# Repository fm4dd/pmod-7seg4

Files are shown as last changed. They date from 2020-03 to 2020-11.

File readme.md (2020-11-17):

## 7SEG4 PMOD

### Description

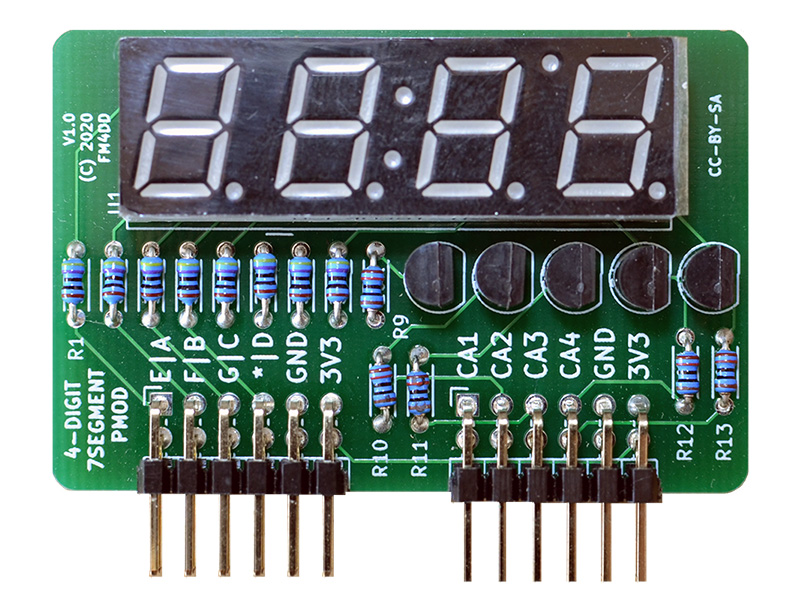
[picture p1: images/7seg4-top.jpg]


This PMOD provides a multiplexed four-digit 7-segment LED display output to FPGA designs via two double-row PMOD ports (quad-row).
The 7-segment display type "common anode" requires to use inverse logic. With inverse logic, setting the output "LOW" lights up the LED segment. Each digit has its own common anode, but the seven LED segments are shared. To display separate numbers on each digit, the program cycles through each anode with the apropriate segments enabled for this digit.

http://fpga.fm4dd.com/

### Schematic
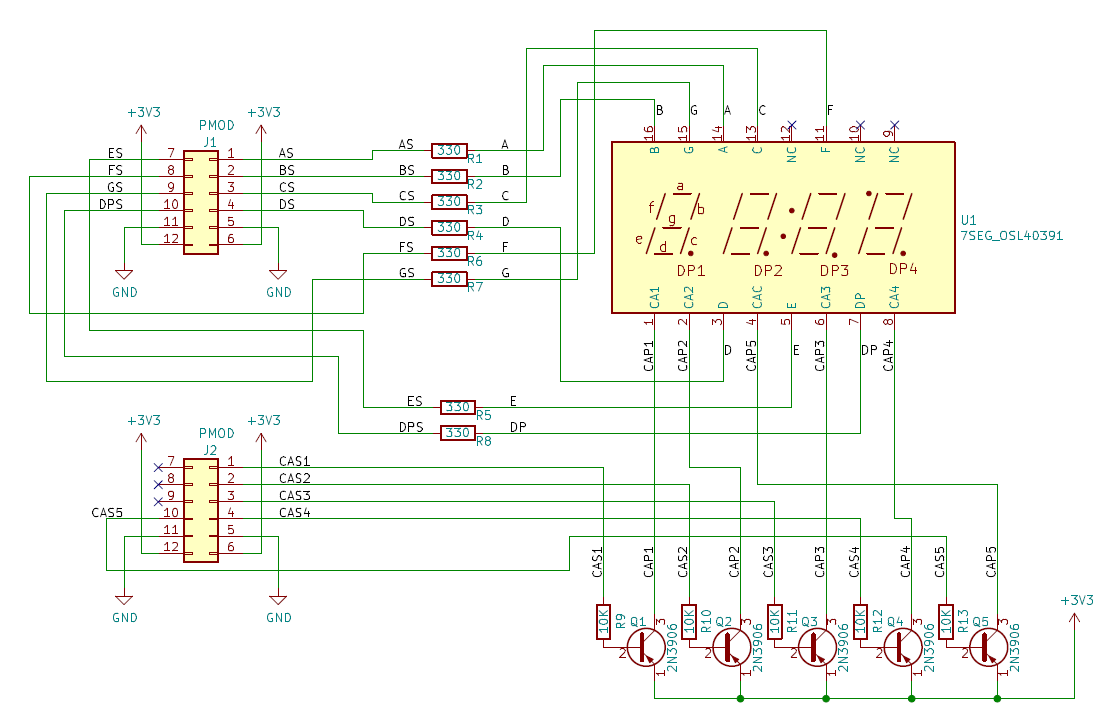
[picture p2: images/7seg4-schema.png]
7SEG4 PMOD Schematics


### PCB Gerber
[7SEG4 PMOD Gerber V1.1](20200130-7seg4-gerber-v11.zip)

### Pin Assignments

#### IceBreaker v1.0

 J1# |  Label | Description   | PMOD1A
-----|--------|---------------|-------
1    |  A     | LED Segment A | 4
2    |  B     | LED Segment B | 2
3    |  C     | LED Segment C | 47
4    |  D     | LED Segment D | 45
7    |  E     | LED Segment E | 3
8    |  F     | LED Segment F | 48
9    |  G     | LED Segment G | 46
10   |  DP    | LED Segment DP| 44

 J2# |  Label | Description      | PMOD1B
-----|--------|------------------|-------
1    |  CA1   | Common AN Digit1 | 43
2    |  CA2   | Common AN Digit2 | 38
3    |  CA3   | Common AN Digit3 | 34
4    |  CA4   | Common AN Digit4 | 31
7    |  -     | Not connected    | 42
8    |  -     | Not connected    | 36
9    |  -     | Not connected    | 32
10   |  CA5   | Common AN Colon  | 28

#### DE0-Nano-SoC

The connection to Intels DE0-Nano-SoC is made through the pmod2nano adapter.

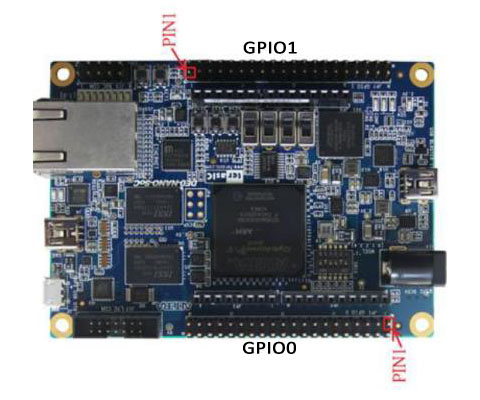
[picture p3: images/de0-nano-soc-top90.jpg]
DE0-Nano-SoC


 J1# |  Label | Description    | GPIO0A | GPIO1A
-----|--------|----------------|--------|--------
1    |  E     |  LED Segment E | PIN_W12|PIN_AA15
2    |  F     |  LED Segment F | PIN_Y8 |PIN_AG26
3    |  G     |  LED Segment G | PIN_W8 |PIN_AF23
4    |  *     |  LED Segment DP| PIN_Y5 |PIN_AF21
7    |  A     |  LED Segment A | PIN_AF8|PIN_AH27
8    |  B     |  LED Segment B | PIN_AB4|PIN_AH24
9    |  C     |  LED Segment C | PIN_Y4 |PIN_AE22
10   |  D     |  LED Segment D | PIN_U11|PIN_AG20

 J2# |  Label | Description      | GPIO0B | GPIO1B
-----|--------|------------------|--------|--------
1    |  -     | Not connected    | PIN_AF4| PIN_AH23
2    |  -     | Not connected    | PIN_AF5| PIN_AE19
3    |  -     | Not connected    | PIN_T13| PIN_AD19
4    |  CA5   | Common AN DP     | PIN_AE7| PIN_AE24
7    |  CA1   | Common AN Digit1 | PIN_AG6| PIN_AG23
8    |  CA2   | Common AN Digit2 | PIN_AE4| PIN_AF18
9    |  CA3   | Common AN Digit3 | PIN_T11| PIN_AE20
10   |  CA4   | Common AN Digit4 | PIN_AF6| PIN_AD20

### Example

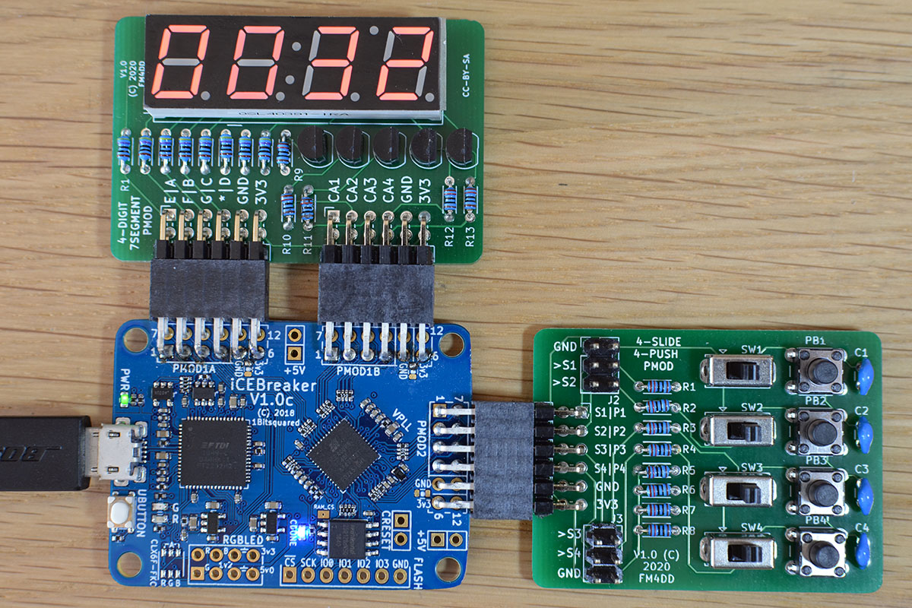
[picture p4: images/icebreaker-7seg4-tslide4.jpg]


7SEG4 PMOD, connected to a Icebreaker v1.0 board

#### Verilog

Verilog test program pmod_7seg4_1.v (top-level):
```
// -------------------------------------------------------
// This program is a decimal counter 0..9999, displayed on
// the 4-digit 7-segment display. Counts in 1Hz intervals.
// 12MHz clock: set breakpoint at 23'd5999999 (icebreaker)
// 50MHz clock: set breakpoint at 25'd24999999 (de0-nano)
// -------------------------------------------------------
module pmod_7seg4_1 (
  input clk,
  output seg_a,
  output seg_b,
  output seg_c,
  output seg_d,
  output seg_e,
  output seg_f,
  output seg_g,
  output seg_dp,
  output ca1,
  output ca2,
  output ca3,
  output ca4
);

  reg clk_1hz = 1'b0;
  reg [22:0] clk_count = 23'd0;
  reg [3:0] DIGIT;
  reg [7:0] SEG;
  assign {seg_dp, seg_g, seg_f, seg_e, seg_d, seg_c, seg_b, seg_a} = SEG;
  assign {ca1, ca2, ca3, ca4} = DIGIT;
  reg [3:0] units, tens, hundreds, thousands;

  display_7seg display(.CLK (clk), .units (units), .tens (tens), .hundreds (hundreds), .thousands (thousands), .SEG (SEG), .DIGIT (DIGIT));

  always @(posedge clk)
  begin
    clk_count   <= clk_count + 1;
    if(clk_count == 23'd5999999)
    begin
      clk_count   <= 0;
      clk_1hz <= ~clk_1hz;
    end
  end

  always @(posedge clk_1hz)
  begin
    units <= units + 1;
    if (units == 9)
    begin
      units <= 0;
      tens <= tens + 1;
      if (tens == 9)
      begin
        tens <= 0;
        hundreds <= hundreds + 1;
        if (hundreds == 9)
        begin
          hundreds <= 0;
          thousands <= thousands + 1;
          if(thousands == 9)
          begin
            thousands <= 0;
          end
        end
      end
    end
  end
endmodule // end top-level module

// -------------------------------------------------------
// module display_7seg converts 4 decimal digits to 7-seg
// -------------------------------------------------------
module display_7seg(
  input CLK,
  input [3:0] units, tens, hundreds, thousands,
  output [7:0] SEG,
  output [3:0] DIGIT
);

  reg [3:0] digit_data;
  reg [1:0] digit_posn;
  reg [23:0] prescaler;

  encode_7seg encode(.CLK (CLK), .SEG (SEG), .D (digit_data));

  always @(posedge CLK)
  begin
    prescaler <= prescaler + 24'd1;
    if (prescaler == 24'd50000)     // set 1kHz multiplex frequency
    begin
      prescaler <= 0;               // reset the prescaler to zero
      digit_posn <= digit_posn + 2'd1;
      if (digit_posn == 0)
      begin
        digit_data <= units;       // assign digit_data
        DIGIT <= 4'b1110;          // set the 1 digit pin low (enable)
      end
      if (digit_posn == 2'd1)
      begin
        digit_data <= tens;        // assign digit_data to show tens
        DIGIT <= 4'b1101;          // set the 2 digit pin low (enable)
      end
      if (digit_posn == 2'd2)
      begin
        digit_data <= hundreds;    // assign digit_data to show hundreds
        DIGIT <= 4'b1011;          // set the 3 digit pin low (enable)
      end
      if (digit_posn == 2'd3)
      begin
        digit_data <= thousands;   // assign digit_data to show thousands
        DIGIT <= 4'b0111;          // set the 4 digit pin low (enable)
        digit_posn <= 0;           // reset position counter after 4nd digit
      end
    end
  end
endmodule

// -------------------------------------------------------
// module encode_7seg encodes a bin number as a 7seg digit
// -------------------------------------------------------
module encode_7seg(
  input CLK,
  input [3:0] D,
  output reg [7:0] SEG
);
  
  always @(posedge CLK)
    begin
      case(D)
        //              PGFEDCBA
        4'd0: SEG <= 8'b11000000;
        4'd1: SEG <= 8'b11111001;
        4'd2: SEG <= 8'b10100100;
        4'd3: SEG <= 8'b10110000;
        4'd4: SEG <= 8'b10011001;
        4'd5: SEG <= 8'b10010010;
        4'd6: SEG <= 8'b10000010;
        4'd7: SEG <= 8'b11111000;
        4'd8: SEG <= 8'b10000000;
        4'd9: SEG <= 8'b10010000;
        default: SEG <= 8'b11111111;
      endcase
    end
endmodule
```

#### VHDL

The Verilog example program pmod_7seg4_1.v converted to VHDL as pmod_7seg4_2.vhd:

```
-- -------------------------------------------------------
-- This program is a decimal counter 0..9999, displayed on
-- the 4-digit 7-segment display. Counts in 1Hz intervals.
-- -------------------------------------------------------
library ieee;
use ieee.std_logic_1164.all;
use ieee.numeric_std.all;

entity pmod_7seg4_2 is
port ( clk: in STD_LOGIC;
     seg_a: out STD_LOGIC := '1';
     seg_b: out STD_LOGIC := '1';
     seg_c: out STD_LOGIC := '1';
     seg_d: out STD_LOGIC := '1';
     seg_e: out STD_LOGIC := '1';
     seg_f: out STD_LOGIC := '1';
     seg_g: out STD_LOGIC := '1';
    seg_dp: out STD_LOGIC := '1';
       ca1: out STD_LOGIC := '1';
       ca2: out STD_LOGIC := '1';
       ca3: out STD_LOGIC := '1';
       ca4: out STD_LOGIC := '1'
);
end pmod_7seg4_2;

architecture arch of pmod_7seg4_2 is
  signal   clk_1hz: STD_LOGIC;
  signal     DIGIT: STD_LOGIC_VECTOR(3 downto 0);
  signal       SEG: STD_LOGIC_VECTOR(7 downto 0);
  signal unit, tens, hundreds, thousands: INTEGER range 0 to 9;

  -- -------------------------
  -- interface to display_7seg
  -- -------------------------
  component display_7seg is
  port ( CLK: IN  STD_LOGIC;
      unit, tens, hundreds, thousands: IN INTEGER := 0;  --digit values
     DIGIT:     OUT STD_LOGIC_VECTOR(3 DOWNTO 0);        --output digit number
                 SEG:   OUT STD_LOGIC_VECTOR(7 DOWNTO 0) --output segments
  );
  end component;

begin
  -- instantiation and value assignment to display_7seg
  display: display_7seg
  port map( clk, unit, tens, hundreds, thousands, DIGIT, SEG );

  counter_p: process( clk, clk_1hz, unit, tens, hundreds, thousands, DIGIT, SEG )
  variable clk_count: INTEGER := 0;

  begin
    if( rising_edge(clk) ) then
    clk_count := clk_count + 1;
      if( clk_count = 24999999 ) then
        clk_count := 0;
        clk_1hz <= NOT clk_1hz;
      end if;
    end if;

    if( rising_edge(clk_1hz) ) then
      unit <= unit + 1;
      if ( unit = 9 ) then
        unit <= 0;
        tens <= tens + 1;
        if ( tens = 9 ) then
          tens <= 0;
          hundreds <= hundreds + 1;
          if ( hundreds = 9 ) then
            hundreds <= 0;
            thousands <= thousands + 1;
            if( thousands = 9 ) then
              thousands <= 0;
            end if;
          end if;
        end if;
      end if;
    end if;
  end process counter_p;

  ca1 <= DIGIT(3);
  ca2 <= DIGIT(2);
  ca3 <= DIGIT(1);
  ca4 <= DIGIT(0);
  seg_a <= SEG(0);
  seg_b <= SEG(1);
  seg_c <= SEG(2);
  seg_d <= SEG(3);
  seg_e <= SEG(4);
  seg_f <= SEG(5);
  seg_g <= SEG(6);
  seg_dp <= SEG(7);
end arch;

-- -------------------------------------------------------
-- entity display_7seg converts 4 decimal digits to 7-seg
-- -------------------------------------------------------
library ieee;
use ieee.std_logic_1164.all;
use ieee.numeric_std.all;

entity display_7seg is
port ( CLK: IN  STD_LOGIC;
      unit: IN INTEGER;
      tens: IN INTEGER;
  hundreds: IN INTEGER;
 thousands: IN INTEGER;
     DIGIT: OUT STD_LOGIC_VECTOR(3 DOWNTO 0);  --output digit number
       SEG: OUT STD_LOGIC_VECTOR(7 DOWNTO 0)   --output segments
);
end display_7seg;

architecture arch of display_7seg is
  signal digit_data: INTEGER;
  -- ------------------------
  -- interface to encode_7seg
  -- ------------------------
  component encode_7seg is
  port( D: IN  INTEGER range 0 to 9;           --digit value input
      SEG: OUT STD_LOGIC_VECTOR(7 DOWNTO 0)    --output to segments
  );
  end component;

begin
  -- instantiation and value assignment to encode_7seg
  encode: encode_7seg port map( digit_data, SEG );

  display: process( clk )
  variable digit_posn: INTEGER range 0 to 3 := 0;
  variable  prescaler: INTEGER := 0;

  begin
  if( rising_edge(clk) ) then
    prescaler := prescaler + 1;
    if( prescaler = 50000 ) then -- 1ms refresh
      prescaler := 0;
      if (digit_posn = 0) then
        digit_data <= unit;      -- assign digit_data
        DIGIT <= "1110";         -- set the 1 digit pin low (enable)
      end if;
      if (digit_posn = 1) then
        digit_data <= tens;      -- assign digit_data to show tens
        DIGIT <= "1101";         -- set the 2 digit pin low (enable)
      end if;
      if (digit_posn = 2) then
        digit_data <= hundreds;  -- assign digit_data to show hundreds
        DIGIT <= "1011";         -- set the 3 digit pin low (enable)
      end if;
      if (digit_posn = 3) then
        digit_data <= thousands; -- assign digit_data to show thousands
        DIGIT <= "0111";         -- set the 4 digit pin low (enable)
      end if;
      digit_posn := digit_posn + 1;
    end if;
  end if;
  end process display;
end arch;

-- -------------------------------------------------------
-- entity encode_7seg encodes a bin number as a 7seg digit
-- -------------------------------------------------------
library ieee;
use ieee.std_logic_1164.all;
use ieee.numeric_std.all;

entity encode_7seg is
port (  D:      IN  INTEGER range 0 to 9;                 --digit value input
                SEG:    OUT STD_LOGIC_VECTOR(7 DOWNTO 0)  --output to segments
);
end encode_7seg;

architecture arch of encode_7seg is
begin
  with D select                       --map input D to segments
    SEG <= "11000000" WHEN 0,         --0
           "11111001" WHEN 1,         --1
           "10100100" WHEN 2,         --2
           "10110000" WHEN 3,         --3
           "10011001" WHEN 4,         --4
           "10010010" WHEN 5,         --5
           "10000010" WHEN 6,         --6
           "11111000" WHEN 7,         --7
           "10000000" WHEN 8,         --8
           "10010000" WHEN 9,         --9
           "11111111" WHEN OTHERS;    --default blank
end arch;
```

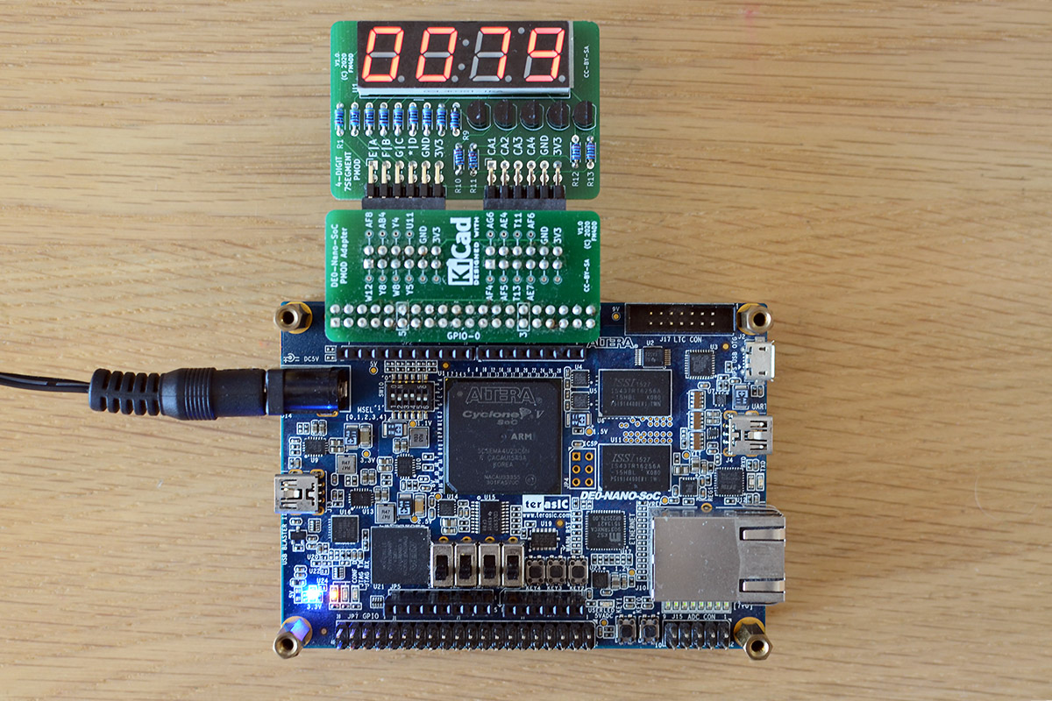
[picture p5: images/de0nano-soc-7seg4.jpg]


7SEG4 PMOD, connected to a DE0-Nano-SoC board

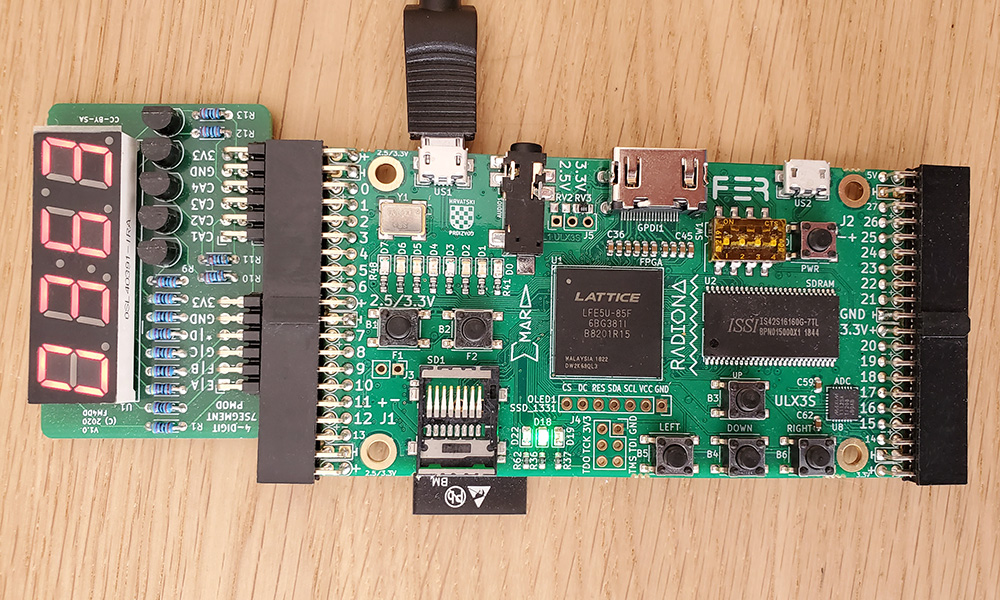
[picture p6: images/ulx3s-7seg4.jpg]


7SEG4 PMOD, connected to a 85K ULX3S board

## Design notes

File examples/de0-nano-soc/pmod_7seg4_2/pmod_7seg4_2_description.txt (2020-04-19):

This program is demonstrating the function of the 7SEG4 PMOD under VHDL.  It implements a decimal counter 0..9999, displayed on the 4-digit 7-segment display. Counts in 1Hz intervals.

The functionality has been converted from the Verilog program pmod_7seg4_1.v, tested on a Icebreaker v1.0 board, using the Linux open source workflow (yosys, nextpnr, and icestorm). Without an open source VHDL workflow, I am testing VHDL on a DE0-Nano-SoC board with Quartus Prime Version 17.1 Lite Edition on Windows.

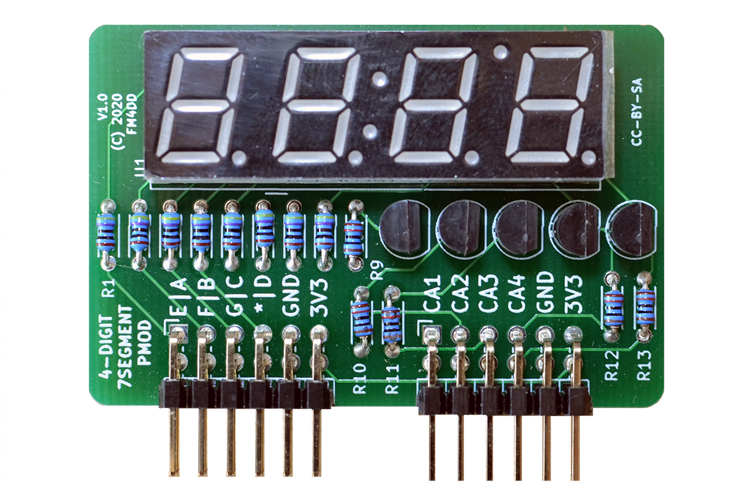
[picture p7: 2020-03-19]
images/7seg4-top-med.png

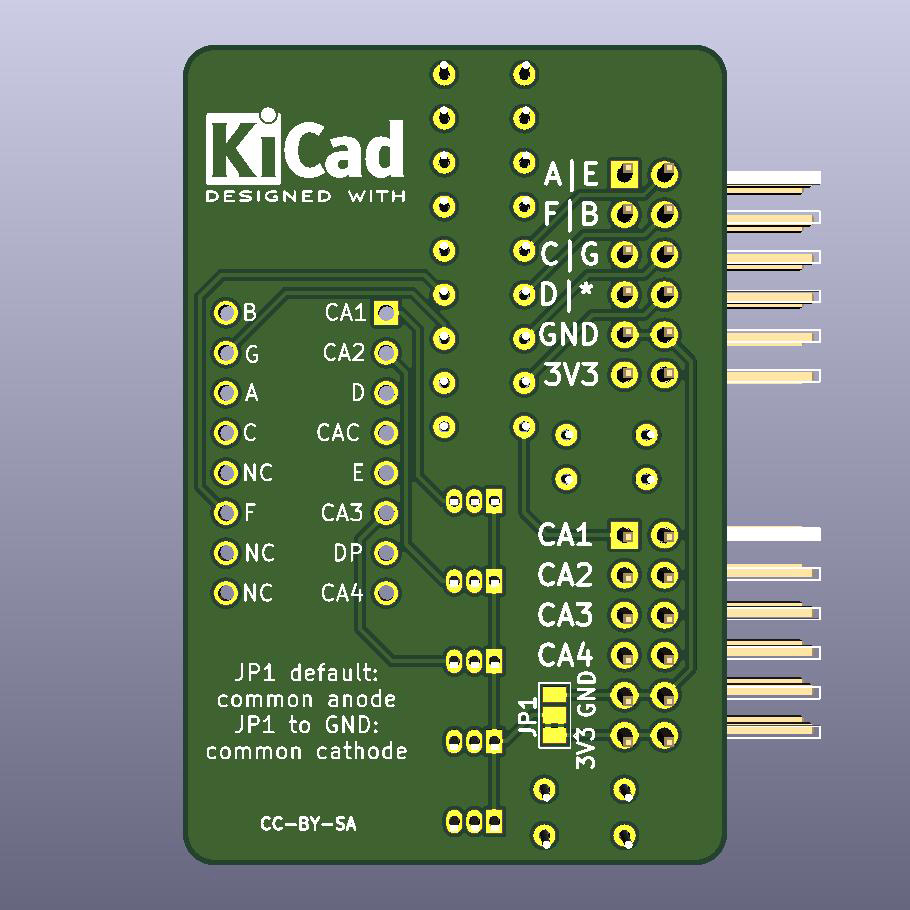
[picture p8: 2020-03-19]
images/7seg4-back v11.jpg

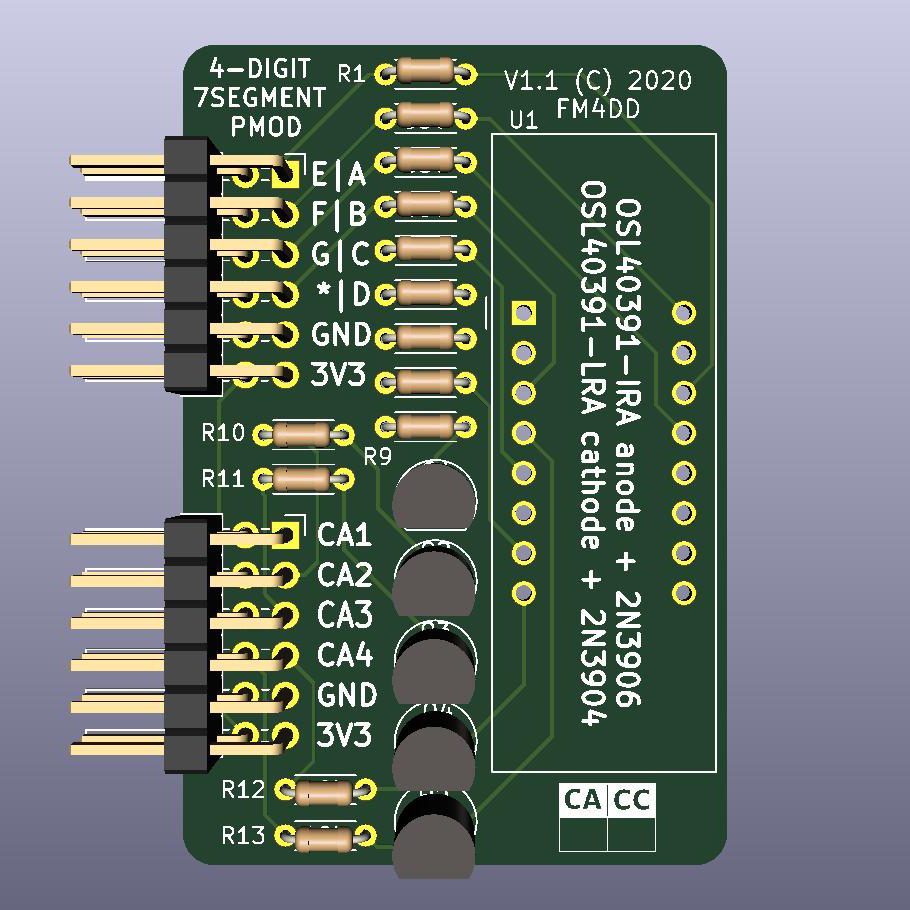
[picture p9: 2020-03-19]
images/7seg4-front v11.jpg

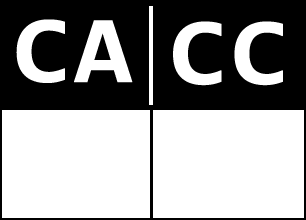
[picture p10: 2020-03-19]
images/type-display.gif

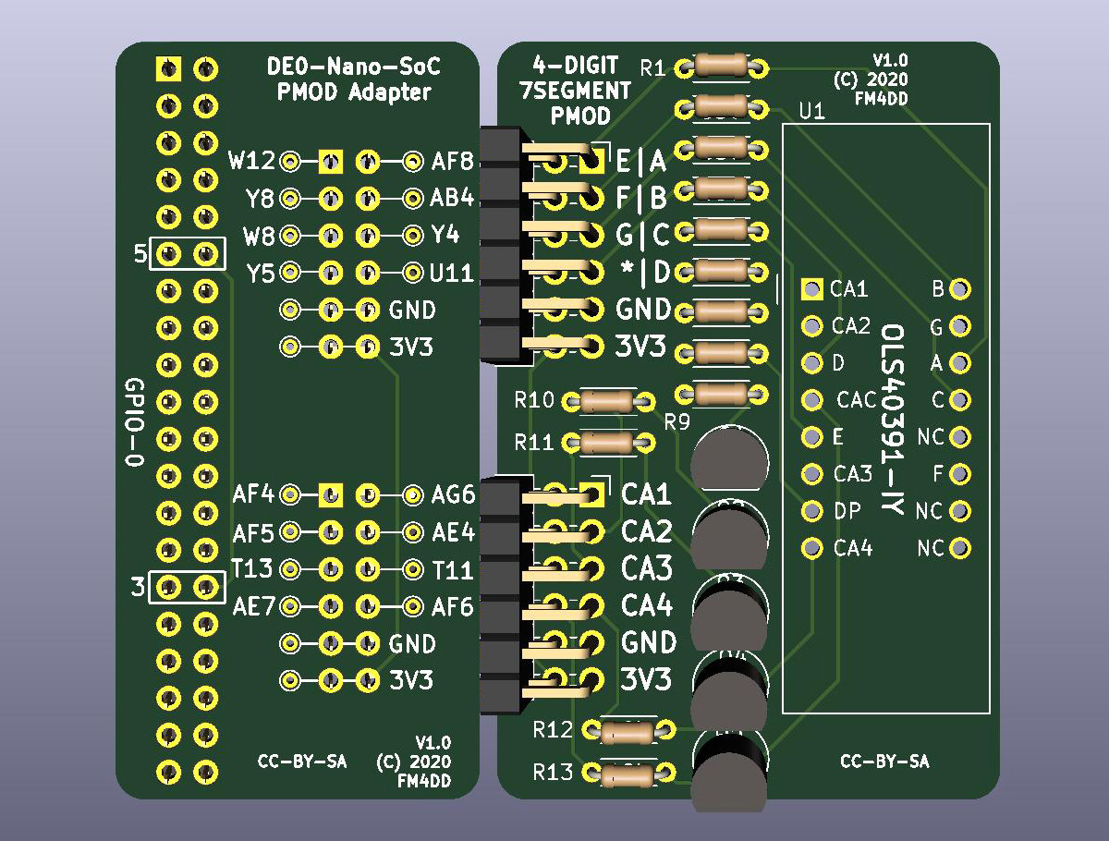
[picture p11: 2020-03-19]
images/7seg4-nano2pmod.jpg

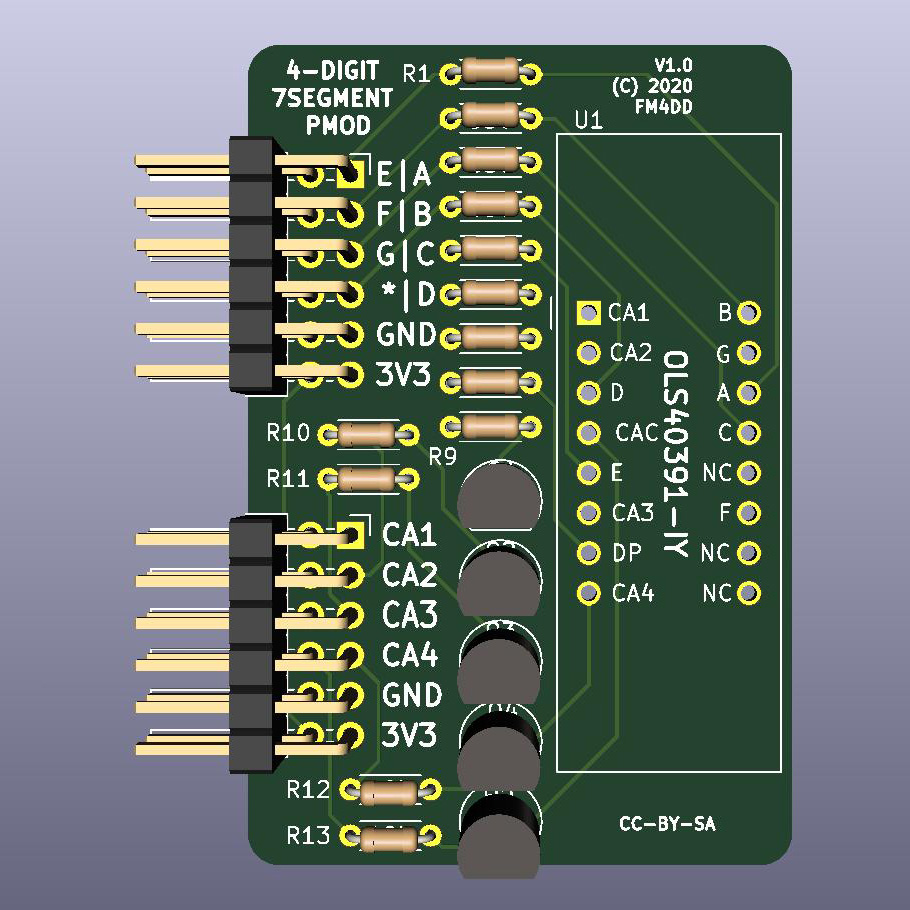
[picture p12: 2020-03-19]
images/7seg4-v10.jpg

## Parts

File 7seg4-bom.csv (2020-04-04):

Manufacturer Part Number | Manufacturer | Digi-Key Part Number | Reference | Quantity | Description
OSL40391-IRA | OptoSupply | N/A, alternative below | U1 | 1 | 0.39" 4-digit 7-Segment Display Common Anode
LTC-4627JR | Lite-On Inc. | 160-1550-5-ND | U1 | 1 | 0.39" 4-digit 7-Segment Display Common Anode
RNMF14FTC470R | Stackpole Electronics Inc | S470CACT-ND | R1-8 | 8 | RES 470 OHM 1/4W 1% AXIAL
RNMF14FTC10K0 | Stackpole Electronics Inc | S10KCACT-ND | R9-13 | 5 | RES 10 KOHM 1/4W 1% AXIAL
2N3906BU | ON Semiconductor | 2N3906FS-ND | Q1-5 | 5 | 2N3906 PNP Silicon Transistor TO-92 Straight Lead
PEC20DBAN | Sullins Connector Solutions | S2112E-20-ND | J1,J2 | 1 | CONN HEADER R/A 40POS 2.54MM cut to size

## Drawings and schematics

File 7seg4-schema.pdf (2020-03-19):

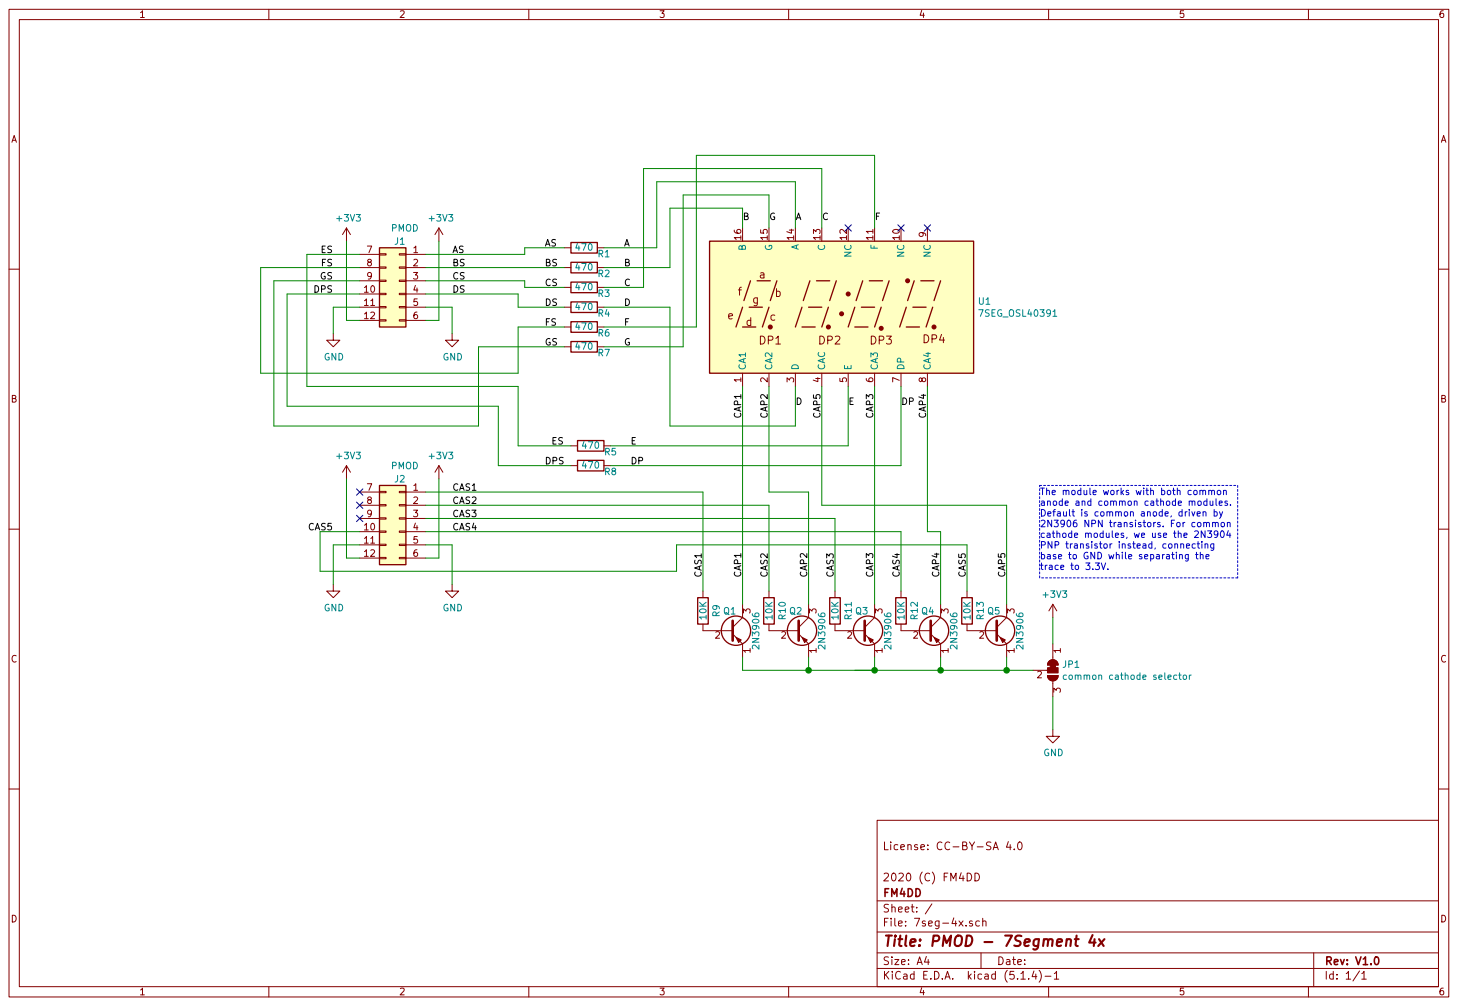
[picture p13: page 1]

8 | | 2 3

11 | | 5
12 | | 6

The module works with both common
anode and common cathode modules. Default is common anode, driven by 2N3906 NPN transistors. For common

11 | 5
12 | 6

cathode modules, we use the 2N3904 PNP transistor instead, connecting

base to GND while separating the
trace to 3.3V.

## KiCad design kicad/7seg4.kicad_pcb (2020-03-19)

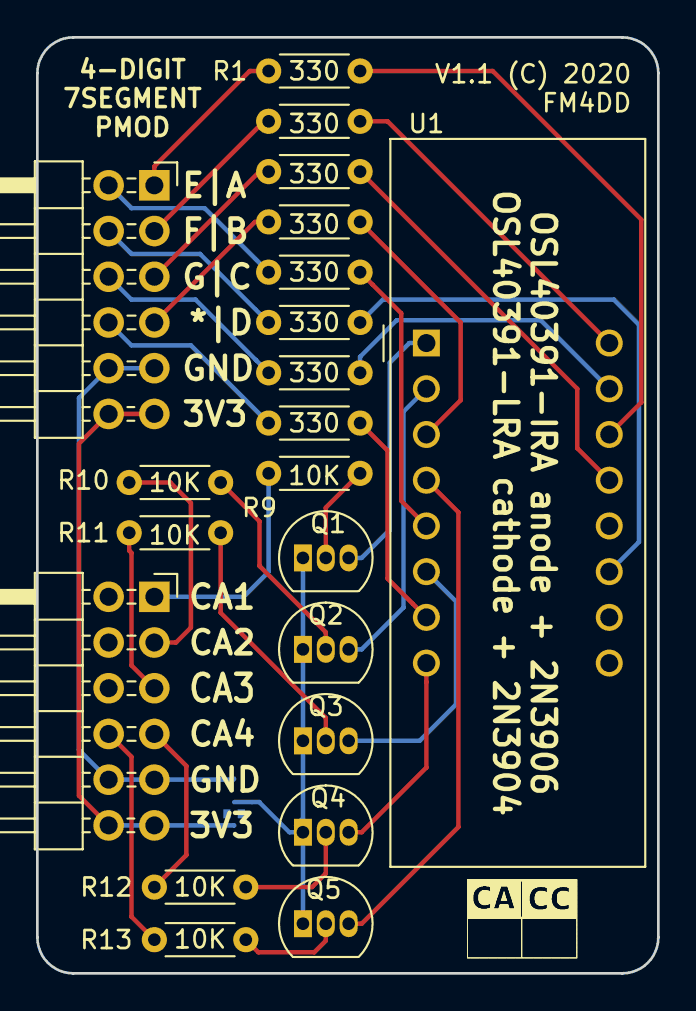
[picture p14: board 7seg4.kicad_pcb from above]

Board: 2 copper layers, 34.5 x 52.0 mm, 23 parts (1 on the bottom side), 34 nets.

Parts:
7seg-type-display: 7seg-type-display
J1, J2: PMOD; PMODHeader_2x06_P2.54mm_Horizontal
JP1: common cathode selector; SolderJumper-3_P1.3mm_Bridged2Bar12_Pad1.0x1.5mm
Q1, Q2, Q3, Q4, Q5: 2N3906; TO-92_Inline
R1, R2, R3, R4, R5, R6, R7, R8: 330; R_Axial_DIN0204_L3.6mm_D1.6mm_P5.08mm_Horizontal
R9, R10, R11, R12, R13: 10K; R_Axial_DIN0204_L3.6mm_D1.6mm_P5.08mm_Horizontal
U1: 7SEG_OSL40391; 7SEG-OSL40391

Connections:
+3V3: J1.6, J1.12, J2.6, J2.12, JP1.1
/A: R1.2, U1.14
/AS: J1.1, R1.1
/B: R2.2, U1.16
/BS: J1.2, R2.1
/C: R3.2, U1.13
/CAP1: Q1.3, U1.1
/CAP2: Q2.3, U1.2
/CAP3: Q3.3, U1.6
/CAP4: Q4.3, U1.8
/CAP5: Q5.3, U1.4
/CAS1: J2.1, R9.1
/CAS2: J2.2, R10.1
/CAS3: J2.3, R11.1
/CAS4: J2.4, R12.1
/CAS5: J2.10, R13.1
/CS: J1.3, R3.1
/D: R4.2, U1.3
/DP: R8.2, U1.7
/DPS: J1.10, R8.1
/DS: J1.4, R4.1
/E: R5.2, U1.5
/ES: J1.7, R5.1
/F: R6.2, U1.11
/FS: J1.8, R6.1
/G: R7.2, U1.15
/GS: J1.9, R7.1
GND: J1.5, J1.11, J2.5, J2.11, JP1.3
unnamed: JP1.2, Q1.1, Q2.1, Q3.1, Q4.1, Q5.1
unnamed: Q1.2, R9.2
unnamed: Q2.2, R10.2
unnamed: Q3.2, R11.2
unnamed: Q4.2, R12.2
unnamed: Q5.2, R13.2

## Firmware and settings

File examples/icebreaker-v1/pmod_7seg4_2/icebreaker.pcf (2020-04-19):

# 12 MHz clock
set_io -nowarn clk        35

# RS232
set_io -nowarn RX          6
set_io -nowarn TX          9

# LEDs and Button
set_io -nowarn BTN_N      10
set_io -nowarn LEDR_N     11
set_io -nowarn LEDG_N     37

# RGB LED Driver
set_io -nowarn LED_RED_N  39
set_io -nowarn LED_GRN_N  40
set_io -nowarn LED_BLU_N  41

# SPI Flash
set_io -nowarn FLASH_SCK  15
set_io -nowarn FLASH_SSB  16
set_io -nowarn FLASH_IO0  14
set_io -nowarn FLASH_IO1  17
set_io -nowarn FLASH_IO2  12
set_io -nowarn FLASH_IO3  13

# PMOD 1A
#set_io -nowarn P1A1        4
#set_io -nowarn P1A2        2
#set_io -nowarn P1A3       47
#set_io -nowarn P1A4       45
#set_io -nowarn P1A7        3
#set_io -nowarn P1A8       48
#set_io -nowarn P1A9       46
#set_io -nowarn P1A10      44

set_io -nowarn seg_a       4
set_io -nowarn seg_b       2
set_io -nowarn seg_c      47
set_io -nowarn seg_d      45
set_io -nowarn seg_e       3
set_io -nowarn seg_f      48
set_io -nowarn seg_g      46
set_io -nowarn seg_dp     44

# PMOD 1B
#set_io -nowarn P1B1       43
#set_io -nowarn P1B2       38
#set_io -nowarn P1B3       34
#set_io -nowarn P1B4       31
#set_io -nowarn P1B7       42
#set_io -nowarn P1B8       36
#set_io -nowarn P1B9       32
#set_io -nowarn P1B10      28

set_io -nowarn ca1        43
set_io -nowarn ca2        38
set_io -nowarn ca3        34
set_io -nowarn ca4        31
set_io -nowarn ca5        28

# PMOD 2
set_io -nowarn P2_1       27
set_io -nowarn P2_2       25
set_io -nowarn P2_3       21
set_io -nowarn P2_4       19
set_io -nowarn P2_7       26
set_io -nowarn P2_8       23
set_io -nowarn P2_9       20
set_io -nowarn P2_10      18

# LEDs and Buttons (PMOD 2)
set_io -nowarn LED1       26
set_io -nowarn LED2       27
set_io -nowarn LED3       25
set_io -nowarn LED4       23
set_io -nowarn LED5       21
set_io -nowarn BTN1       20
set_io -nowarn BTN2       19
set_io -nowarn BTN3       18

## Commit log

2020-04-04 fix pin assignment and add VHDL example
2020-11-17 add ULX3S board example

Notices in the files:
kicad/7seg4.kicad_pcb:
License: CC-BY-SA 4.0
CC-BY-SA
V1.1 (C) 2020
